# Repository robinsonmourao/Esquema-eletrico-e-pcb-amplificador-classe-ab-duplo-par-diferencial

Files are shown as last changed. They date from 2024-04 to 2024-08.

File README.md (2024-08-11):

# 3.0
## SCHEME
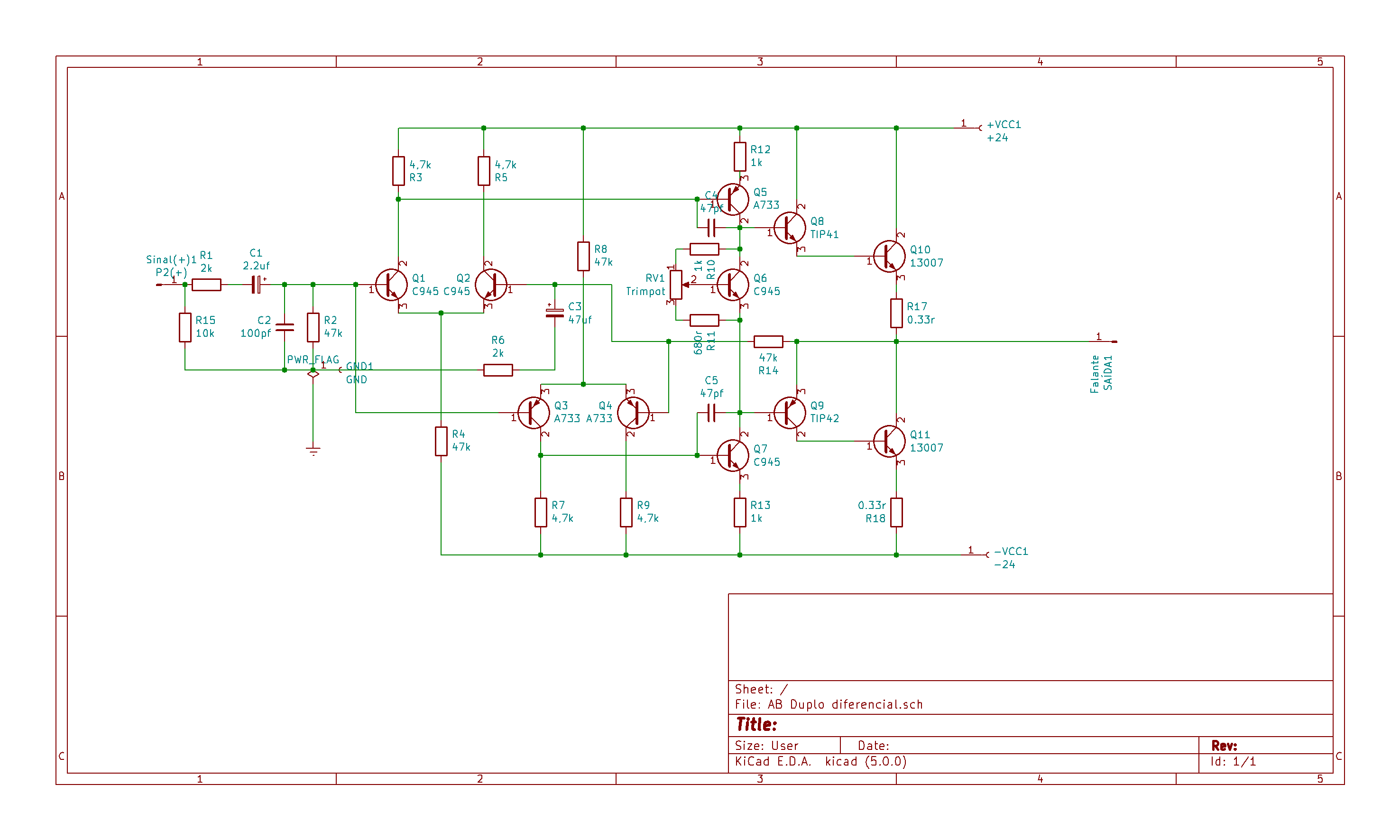
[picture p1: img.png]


## PCB
### ORIGINAL
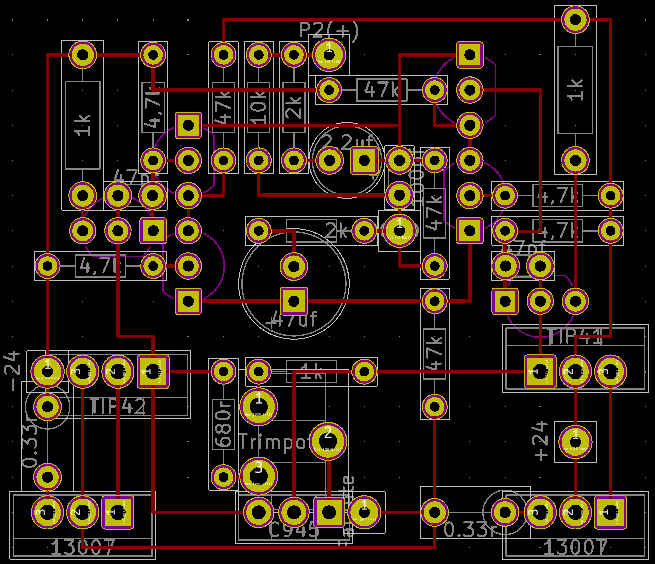
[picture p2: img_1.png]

### INVERTIDO HORIZONTALMENTE
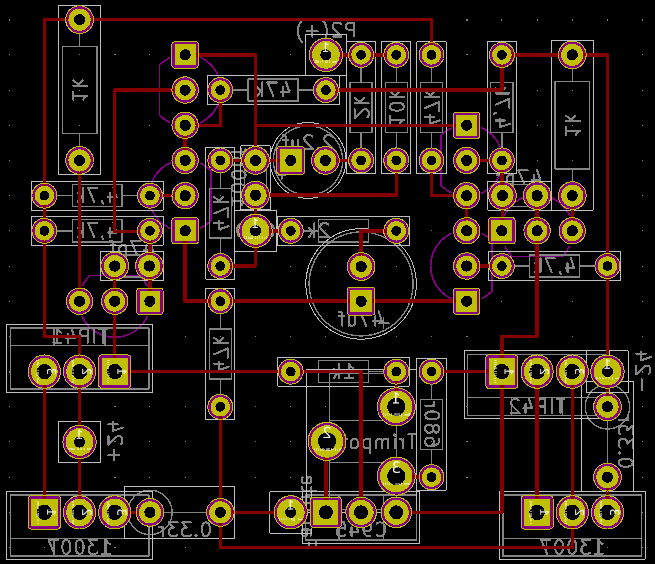
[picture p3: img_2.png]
 

## MODELO FÍSICO
### SUPERIOR
`Desatualizado`


### INFERIOR
`Desatualizado`


# 2.1 beta - 2.0
## SCHEME


## PCB
### ORIGINAL

### INVERTIDO HORIZONTALMENTE


## MODELO FÍSICO
### SUPERIOR 2.1 beta
`versão não funcionou`

### INFERIOR 2.1 beta
`versão não funcionou`

### SUPERIOR 2.0

### INFERIOR 2.0


# 1.0
## SCHEME


## PCB
### ORIGINAL

### INVERTIDO HORIZONTALMENTE


## MODELO FÍSICO
### SUPERIOR
`INEXISTENTE`
### INFERIOR
`25-0-25`_1

`25-0-25`_2


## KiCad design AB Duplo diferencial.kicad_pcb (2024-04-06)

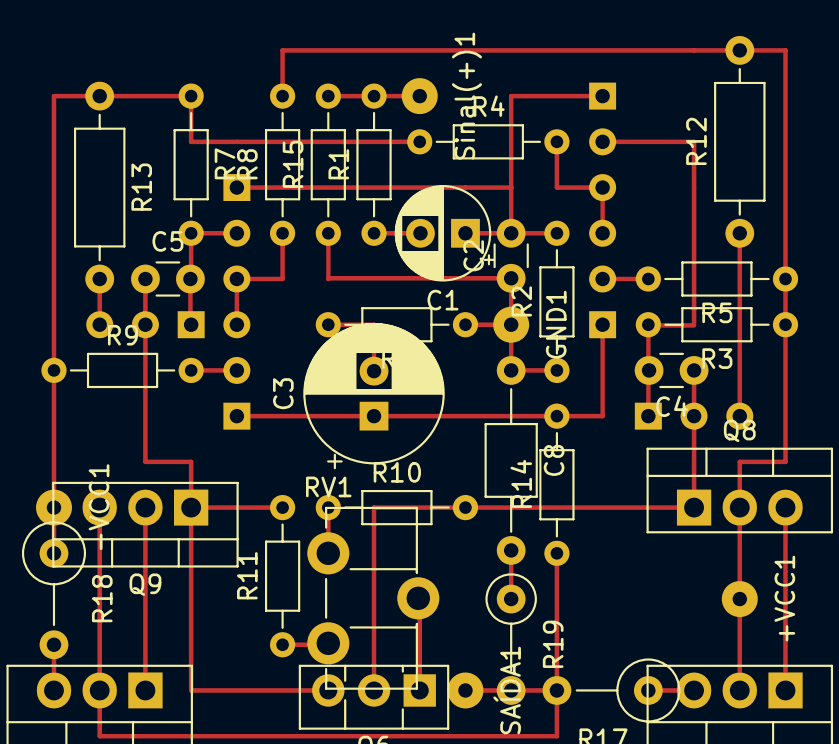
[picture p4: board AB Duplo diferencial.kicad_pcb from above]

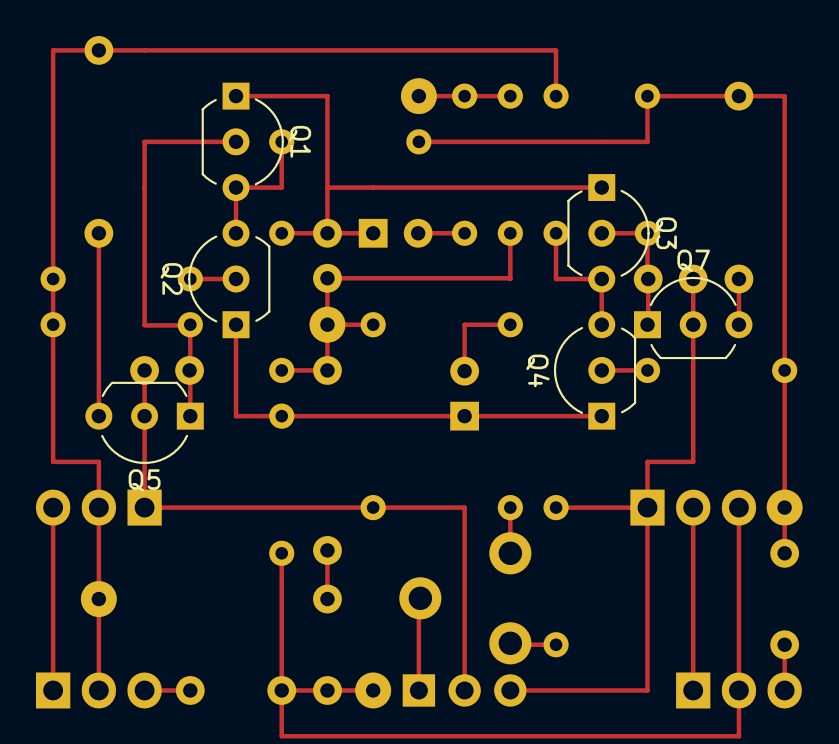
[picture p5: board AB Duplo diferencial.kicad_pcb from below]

Board: 2 copper layers, 41 parts (6 on the bottom side), 27 nets.

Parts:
+VCC1: +24; SolderWirePad_1x01_Drill0.8mm
-VCC1: -24; SolderWirePad_1x01_Drill0.8mm
C1: 2.2uf; CP_Radial_D5.0mm_P2.50mm
C2: 100pf; C_Disc_D3.0mm_W1.6mm_P2.50mm
C3: 47uf; CP_Radial_D7.5mm_P2.50mm
C4, C5: 47pf; C_Disc_D3.0mm_W1.6mm_P2.50mm
C8: 0,1uf; C_Axial_L3.8mm_D2.6mm_P10.00mm_Horizontal
GND1: GND; SolderWirePad_1x01_Drill0.8mm
Q1, Q2, Q7: C945; TO-92_Inline_Wide
Q3, Q4, Q5: A733; TO-92_Inline_Wide
Q6: C945; TO-126-3_Vertical
Q8: TIP41; TO-220-3_Vertical
Q9: TIP42; TO-220-3_Vertical
Q10, Q11: 13007; TO-220-3_Vertical
R1, R6: 2k; R_Axial_DIN0204_L3.6mm_D1.6mm_P7.62mm_Horizontal
R2, R4, R8, R14: 47k; R_Axial_DIN0204_L3.6mm_D1.6mm_P7.62mm_Horizontal
R3, R5, R7, R9: 4,7k; R_Axial_DIN0204_L3.6mm_D1.6mm_P7.62mm_Horizontal
R10: 1k; R_Axial_DIN0204_L3.6mm_D1.6mm_P7.62mm_Horizontal
R11: 680r; R_Axial_DIN0204_L3.6mm_D1.6mm_P7.62mm_Horizontal
R12, R13: 2k; R_Axial_DIN0207_L6.3mm_D2.5mm_P10.16mm_Horizontal
R15: 10k; R_Axial_DIN0204_L3.6mm_D1.6mm_P7.62mm_Horizontal
R17, R18: 0.33r; R_Axial_DIN0309_L9.0mm_D3.2mm_P5.08mm_Vertical
R19: 10r; R_Axial_DIN0207_L6.3mm_D2.5mm_P5.08mm_Vertical
RV1: Trimpot; Potentiometer_ACP_CA9-H5_Horizontal
SAÍDA1: Falante; SolderWirePad_1x01_Drill0.8mm
Sinal(+)1: P2(+); SolderWirePad_1x01_Drill0.8mm

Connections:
Earth: C2.1, C8.1, GND1.1, R2.1, R6.1, R15.1
unnamed: +VCC1.1, Q8.2, Q10.2, R3.1, R5.1, R8.2, R12.2
unnamed: -VCC1.1, R4.1, R7.1, R9.1, R13.1, R18.1
unnamed: C1.1, C2.2, Q1.1, Q3.1, R2.2
unnamed: C1.2, R1.1
unnamed: C3.1, Q2.1, Q4.1, R14.2
unnamed: C3.2, R6.2
unnamed: C4.1, Q5.2, Q6.2, Q8.1, R10.2
unnamed: C4.2, Q1.2, Q5.1, R3.2
unnamed: C5.1, Q6.3, Q7.2, Q9.1, R11.2
unnamed: C5.2, Q3.2, Q7.1, R7.2
unnamed: C8.2, R19.1
unnamed: Q1.3, Q2.3, R4.2
unnamed: Q2.2, R5.2
unnamed: Q3.3, Q4.3, R8.1
unnamed: Q4.2, R9.2
unnamed: Q5.3, R12.1
unnamed: Q6.1, RV1.2
unnamed: Q7.3, R13.2
unnamed: Q8.3, Q10.1
unnamed: Q10.3, R17.1
unnamed: Q9.2, Q11.1
unnamed: Q9.3, Q11.2, R14.1, R17.2, R19.2, SAÍDA1.1
unnamed: Q11.3, R18.2
unnamed: R1.2, R15.2, Sinal(+)1.1
unnamed: R10.1, RV1.1
unnamed: R11.1, RV1.3

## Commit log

2024-02-25 Otimizadas algumas trilhas & adicionado resistor 4.7k da entrada pro terra para reduzir o ruído de 60hz
    [AB Duplo diferencial.kicad_pcb, AB Duplo diferencial.sch]
2024-02-25 Alteradas rotas para R7 e R11 & expandido placa geral 1 furo para esquerda
    [AB Duplo diferencial.kicad_pcb, AB Duplo diferencial.sch]
2024-02-25 Reordenação de 20 para 17 linhas na vertical para encaixar dois projetos em uma placa de 15x34
    [AB Duplo diferencial.kicad_pcb]
2024-03-16 [trocados de posição] C4 e Q5, C5 e Q7 para que a filtragem do capacitor venha antes da base [otimizado] R5 direto para Q2 [rotacionado] R3 para mesma orientação de R5 [encurtado] trilha entre -VCC e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
    [AB Duplo diferencial.kicad_pcb]
2024-03-16 [centralizados] Nomes nos próprios componentes do pcb
    [AB Duplo diferencial.kicad_pcb]
2024-03-17 [atualizados] Valores: C7(47uf) & R2/R14(100k) & R12/R13(2K) & R15(10K) [renomeados] "Sinal(+)" para "P2" & +VCC1 para "+24" & "-VCC1" para "-24" & "SAÍDA" para "Falante"
    [AB Duplo diferencial.kicad_pcb, AB Duplo diferencial.sch]
2024-03-30 [rotacionados] C3 e R6 para facilitar a ligação entre Q2 e Q4
    [AB Duplo diferencial.kicad_pcb]
2024-04-06 [rollback] R2 & R14 pra 47k [alterado] C4 & C5 pra 47pf
    [AB Duplo diferencial.kicad_pcb, AB Duplo diferencial.sch]
2024-04-06 [desabilitado] camadas F.SilkS, B.CrtYd e B.Fab de PcbView
    [AB Duplo diferencial.kicad_pcb]
2024-04-06 [corrigido] TO-92_Inline pra TO-92_Inline_Wide & visão 3d no PcbView
    [AB Duplo diferencial.kicad_pcb, AB Duplo diferencial.sch]
2024-04-06 [corrigido] Readme.md TO-92_Inline pra TO-92_Inline_Wide & visão 3d no PcbView
2024-04-07 [Alterado] versão 3.0 beta para 2.1 beta
2024-08-11 [corrigido][esquema][layout]R12 & R13 de 2k para 1k [removido][esquema][layout]R19 & C8
